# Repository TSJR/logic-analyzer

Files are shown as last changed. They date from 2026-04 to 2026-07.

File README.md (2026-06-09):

# TTL Logic Analyzer

Breadboard and PCB-based logic analyzer built from discrete 74xx TTL logic, SRAM, and multiplexed LED matrix displays.

## Overview
This project aims to build a fully discrete logic analyzer without using a microcontroller. The analyzer captures digital bus states into SRAM and displays captured samples on multiplexed LED matrices.

Project is currently in a state of active prototyping.

*This repository also contains a [closely related project](attiny-logic-analyzer) using an MCU-based design with 24 channels. 

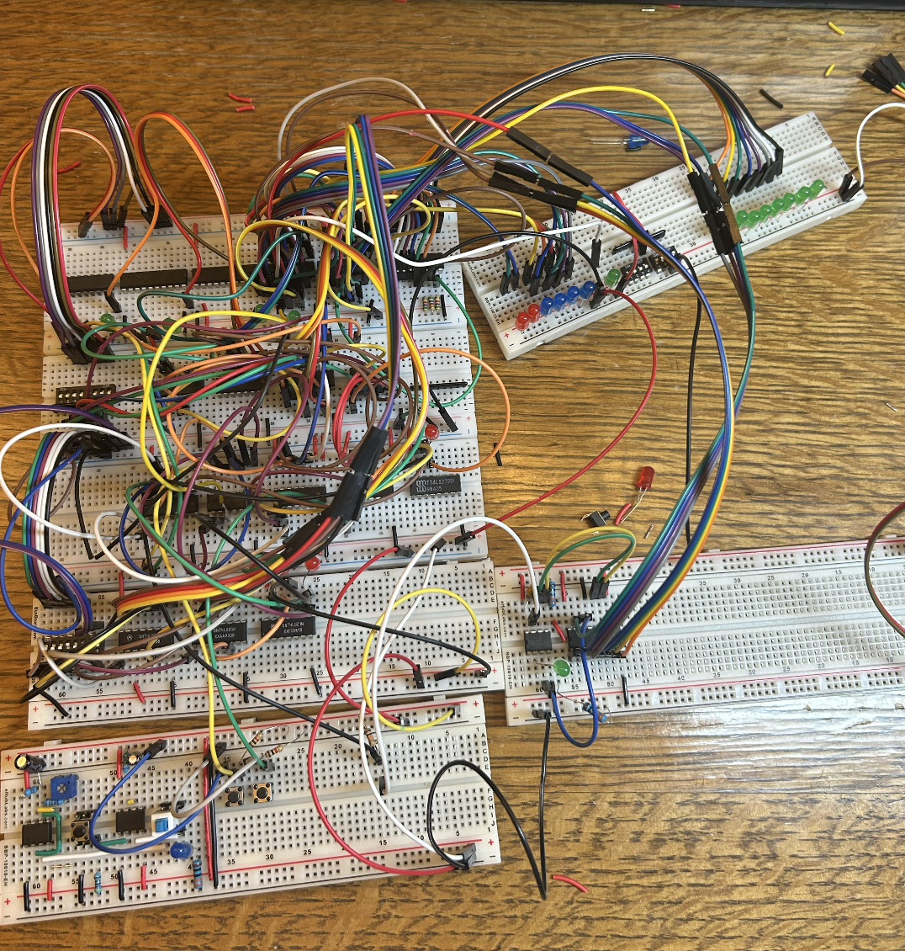
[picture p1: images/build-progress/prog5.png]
Current prototype


## Features
- Fully TTL-based architecture
- SRAM-based sample capture
- Multiplexed LED matrix display
- External/internal clock modes
- Planned trigger and halt functionality
- Modular PCB-based design

## Current Status
Current prototype supports:
- 64ish x 8 sample memory subsystem
- LED matrix display driver
- Breadboard proof-of-concept testing

Known issues:
- Breadboard noise/signal integrity
- Clock edge instability
- Limited memory

## Architecture
Main subsystems:
- Capture memory subsystem
- Address/control logic
- Clock generation and edge conditioning
- Display subsystem

## Relevant Simulation Subcircuits
- `analyzer_7400.circ` — 74xx IC Implementation     
    - **mem_64x8**: Full memory subsystem test built from 74xx-style chips using four `ram_unit` subcircuits.
    - **ram_unit**: 16x8 RAM unit built from 74xx-style chips; used as the building block for `mem_64x8`.
    - **disp_16x16**: Limited-capacity display subsystem test; does not yet include the physical driver circuitry needed for hardware.
- `analyzer_ttl.circ` — Abstract Logic Implementation
    - **mem_64x8_async**: Asynchronous version of the 64x8 memory subsystem; same capacity as the final intended design.
    - **disp_16x32**: Full-capacity display subsystem test.

More detailed documentation:
- [Analyzer Architecture](docs/architecture.md)
- [Build Log](docs/build-log.md)
- [Simulation Subcircuits](simulations/sim-subcircuits.md)

## Repository Structure
```text
docs/                   Docs and architecture notes
images/                 Build photos and diagrams
pcb/                    KiCad PCB projects
simulations/            Logisim simulations
attiny-logic-analyzer/   Related MCU-based project
```

## Hardware
Main IC families/components:
- 74xx logic family chips
- ULN2803 and UDN2981

## Future Plans
- Expand memory depth
- Modular memory pcb
- Trigger logic
- Improved clock conditioning
- PCB-based final implementation

If the project expands beyond basic TTL hardware, plans may include
- USB interface
- OLED display
- Many more channels
- Higher sampling rate 

## License
MIT License

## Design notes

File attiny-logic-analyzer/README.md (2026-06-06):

### ATtiny Logic Analyzer
24-channel ATtiny85-based logic analyzer built on a custom PCB

## Overview
This project is a tool for use in debugging other projects. It reads from 24 data inputs using 3 `74LS595` chips connected to the ATtiny85. The ATtiny then displays the inputs on an LCD screen via I2C protocol. It is asynchronous, meaning it displays what data is being read at all times, and it does not store read data. This makes it unusable for situations where consecutive sample rates are necessary, but it's helpful for taking a look at the state of a system one sample at a time. 

The first prototype of the project is complete.

## Features
- 24 channel analysis
- `74LS595` shift registers for many inputs
- ATtiny MCU
- 16x2 LCD via I2C protocol
- 3D printed housing

## Repository Structure
```text
code/               Arduino code
images/             Images of schematics and builds
models/             3D model files (STLs designed with onshape)
pcb/                KiCad schematic and PCB design
```

## License
MIT License

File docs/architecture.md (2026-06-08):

# TTL Logic Analyzer Architecture 
## Overview
- Analyzer is comprised of two halves
    - **Memory Subsystem**
    - **Display Subsystem**
- Operates in read or write mode
    - Read mode: data is read from **Memory Subsystem** and is output on the **Display Subsystem**
    - Write mode: on each clock pulse, data from target device is sequentially saved into **Memory Subsystem**
## Design Goals
- Entire system built on 74xx chips (no MCU)
- Modular enough to increase memory capacity/display size
- Capable of capturing 64 samples
- Capable of displaying samples with vertical and horizontal scrolling
## Analyzer I/O
### Target device connections
- **CLK**: target device clock
- **Data In**: 8 channels of target device
- **GND**: common ground between analyzer and target device
### System Controls
- **RUN** (active LOW): enables write mode 
- **HLT** (active HIGH): enables read mode
- **HLT Word EN** (active HIGH): enables word-based halting 
- **HLT Word**: defines 8-bit input where the analyzer should halt
## Example Usage
1. **HLT Word EN** is tied low to disable word-based halting
2. **CLK**, **Data In**, and **GND** are connected to target device
3. **RUN** is briefly pulled LOW, putting analyzer into write mode
4. On each clock pulse, data from the target device is saved to the **Memory Subsystem**
5. **HLT** is briefly pulled HIGH, putting the analyzer into read mode
6. The **Display Subsystem** addresses data from the **Memory Subsystem** and displays it on LED matrices

## Memory Subsystem Architecture
The memory subsystem captures 8-bit parallel data from a target device and stores sequential samples into RAM using an internally clocked address counter.  

**Capacity**: 64 samples x 8-bit sample size

___
### Memory Subsystem Interface
Inputs:
- **CLK**: target clock used for sampling
- **Data In**: 8-bit captured input bus
- **RUN**: enters write mode
- **HLT**: enters read mode
- **HLT Word EN**: enables automatic halt matching
- **HLT Word**: 8-bit halt-match value
- **Address In**: external read address from **Display Subsystem**

Outputs:
- **Data Out**: 8-bit stored sample output to **Display Subsystem**
- **R/W State**: current analyzer mode
___
## Memory Subsystem Organization
### R/W Mode Control
R/W state is stored in SR-latch  
- SR-latch set = write mode  
- SR-latch reset = read mode

The latch is manually reset through briefly bringing the **HLT** signal high or automatically through word-based halting logic. The latch is reset by briefly bringing the **RUN** signal high
___
### RAM Units (4 total)
Each unit is constructed with:
- 1 RAM chip for high 4 bits
- 1 RAM chip for low 4 bits
- 1 octal tri-state buffer
Total of 16 samples with 8 bits of data per unit

Demultiplexer chip uses upper 2 address bits to select active RAM unit (both both RAM and buffer side)

All tri-state buffer outputs connect forming the data bus. Since the `74189` chip has inverted outputs, the bus must be negated with hex inverters before becoming **Data Out**
___
### Addressing
System supports internal (**Memory Subsystem**'s 6-bit counter) and external addressing (**Display Subsystem**'s 6-bit counter)

Internal addressing (write mode)
- Clock pulse advances the **Memory Subsystem**'s counter
- **Data In** is written into memory

External addressing (read mode)
- **Display Subsystem** is able to cherry pick saved data from the **Memory Subsystem** and display it

In both addressing modes, the upper 2 address bits select a RAM unit and lower 4 address bits select the current location in memory
___
### Clocking and Write Control
Two operations per clock cycle during write mode
- On rising edge, data is written to RAM
- On falling edge, internal counter is incremented
**Data In** is only written to the demultiplexer's selected RAM unit

Clock is ignored in read mode as memory contents are to be accessed asyncronously
___
### Halting Modes
- Word-based Halting
    - Enters read mode when **Data In** matches user-defined 8-bit sequence **HLT Word** on clock pulse. Mode is only available when **HLT Word EN** is tied high
- Manual Halting
  - Enters read mode when **HLT** is pulled high
  - Available regardless of **HLT Word EN**'s state.

Neither halting mode takes a data sample when the halt word is detected to maximize the analyzer's limited memory

## Operating Mode Flows
### Read Mode
1. System is halted
   -  **HLT** pulled high or **Data In** matches **HLT Word** during word-based halting mode
2. SR-latch is reset
3. Selector chips route **Address In**, allowing **Display Subsystem** to address **Memory Subsystem** asyncronously
### Write Mode
1. **Run** is pulled high
2. SR-latch is set
3. Selector chips route internal counter
4. Internal counter is reset
5. High clock pulse writes data into RAM at memory location
6. Low clock pulse advances counter and targets next RAM memory location
n 

## Current Limitations
- 64 total samples
- 8-channel capture width
- May only work with low-frequency systems
- No internal clock
- No timestamp tracker

## Future Improvements
- 128 samples and/or 16-channel capture width
- Less primitive display (higher resolution/colors)
- Internal clock implementation
  - User-defined sample rate
  - Manual sampling with button
- If project moves away from being exclusively TTL
  - USB interface
  - Microcontroller usage
  - RAM upgrade (eg. 6116 or 6264 SRAM)

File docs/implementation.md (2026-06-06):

# TTL Logic Analyzer Implementation
## Overview
- Analyzer is comprised of two halves
    - **Memory Subsystem**
    - **Display Subsystem**
- Operates in read or write mode
    - Read mode: data is read from **Memory Subsystem** and is output on the **Display Subsystem**
    - Write mode: on each clock pulse, data from target device is sequentially saved into **Memory Subsystem**
## Memory Subsystem
### 74xx Hardware
- 8 `74189` RAMs
- 2 `74LS157` selectors
- 2 `74LS161` binary counters 
- 2 `74LS14` hex inverter/schmitt trigger
- 1 `74LS32` OR gate chip
- 2 `74LS85` 4-bit comparators
- 1 `74LS21` quad input AND gate
- 1 `74LS279` SR-latch chip
- 4 `74LS245` octal tristate buffers
- 2 `74LS08` AND gates
- 1 `74LS139` decoder
### Additional Hardware
- 8x `1088AS` 8x8 dot matrix
- 32x 5-10k pullup resistors
- unknown amount of breadboards
- a lot of wires

## Build
### RAM Units
The memory subsystem contains 4 RAM units. Each RAM unit is comprised of:
- 2 `74189` 16x4 RAM ICs
- 8 pullup resistors
- 1 `74LS245` octal tri-state buffer

Connections are as follows:
- **Data In Bus**[7:4] to data inputs of first `74189`
-  **Data In Bus**[3:0] to data inputs of second `74189`
- All 8 `74189` outputs are pulled high and connected to side A of `74LS245`
- Side B of `74LS245` is connected to **Data Out Bus**
- The `74LS245` is wired for A->B operation

## Display Subsystem
## Timing/Control Logic
## Bus Architecture
### Data Bus
### Address Bus
## Known Issues
## Implementation notes

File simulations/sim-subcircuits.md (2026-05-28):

# Simulation Subcircuits

## `analyzer_7400.circ` — 74xx IC Implementation

- **main**: Current implementation connecting the memory subsystem (`mem_16x8`) to the display subsystem (`disp_16x16`).
- **mem_64x8**: Full memory subsystem test built from 74xx chips using 4 `ram_unit` subcircuits.
- **ram_unit**: 16x8 RAM unit built from 74xx  chips; used as building block for `mem_64x8`.
- **mem_16x8**: Limited-capacity memory subsystem test; reflects the current working design
- **disp_16x16**: Limited-capacity display subsystem test; does not include the physical driver circuitry needed for hardware

## `analyzer_ttl.circ` — Abstract Logic Implementation

- **main**: Current implementation connecting `mem_64x8_async` to the display subsystem (`disp_16x32`).
- **mem_64x8_async**: Asynchronous version of the 64x8 memory subsystem; same capacity as the final intended design
- **mem_64x8**: Original 64x8 memory subsystem design; same capacity as the final intended design
- **disp_16x32**: Full-capacity display subsystem test

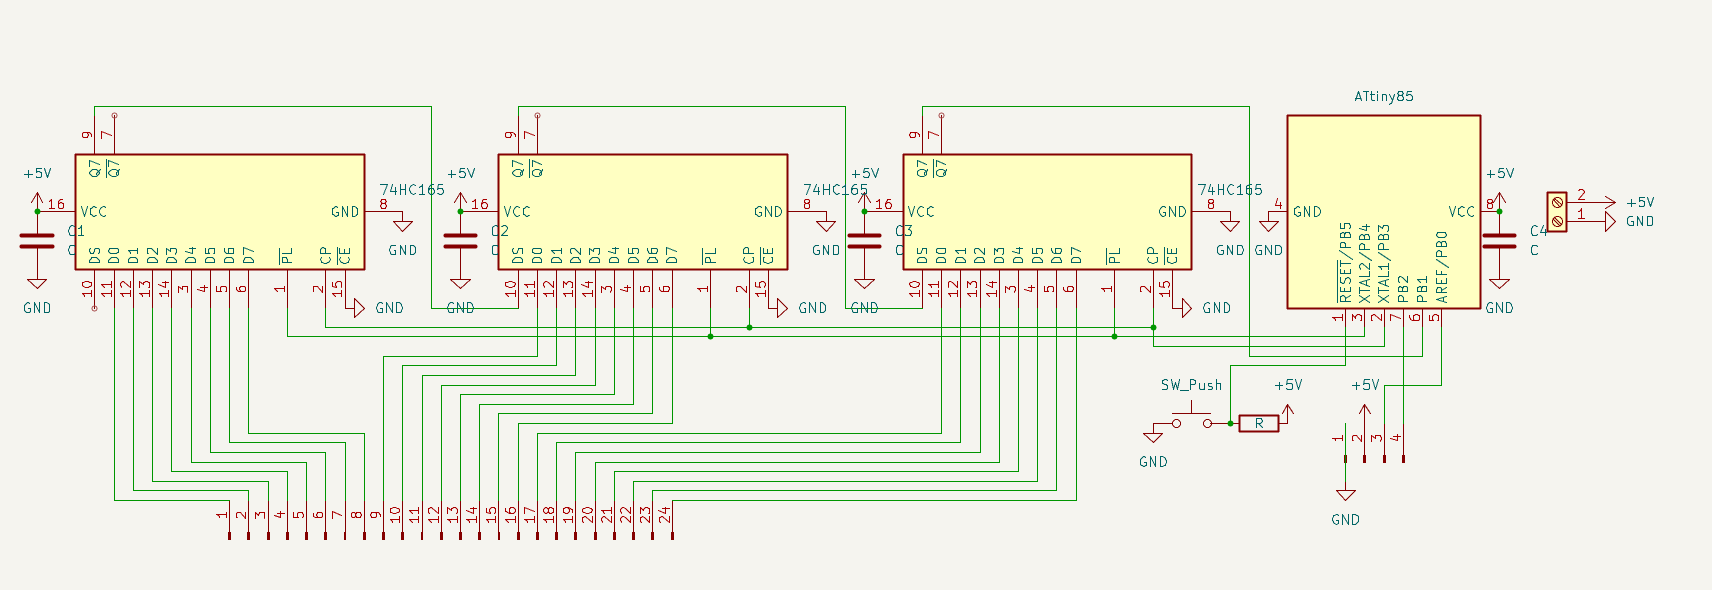
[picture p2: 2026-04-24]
attiny-logic-analyzer/images/attiny_schematic.png

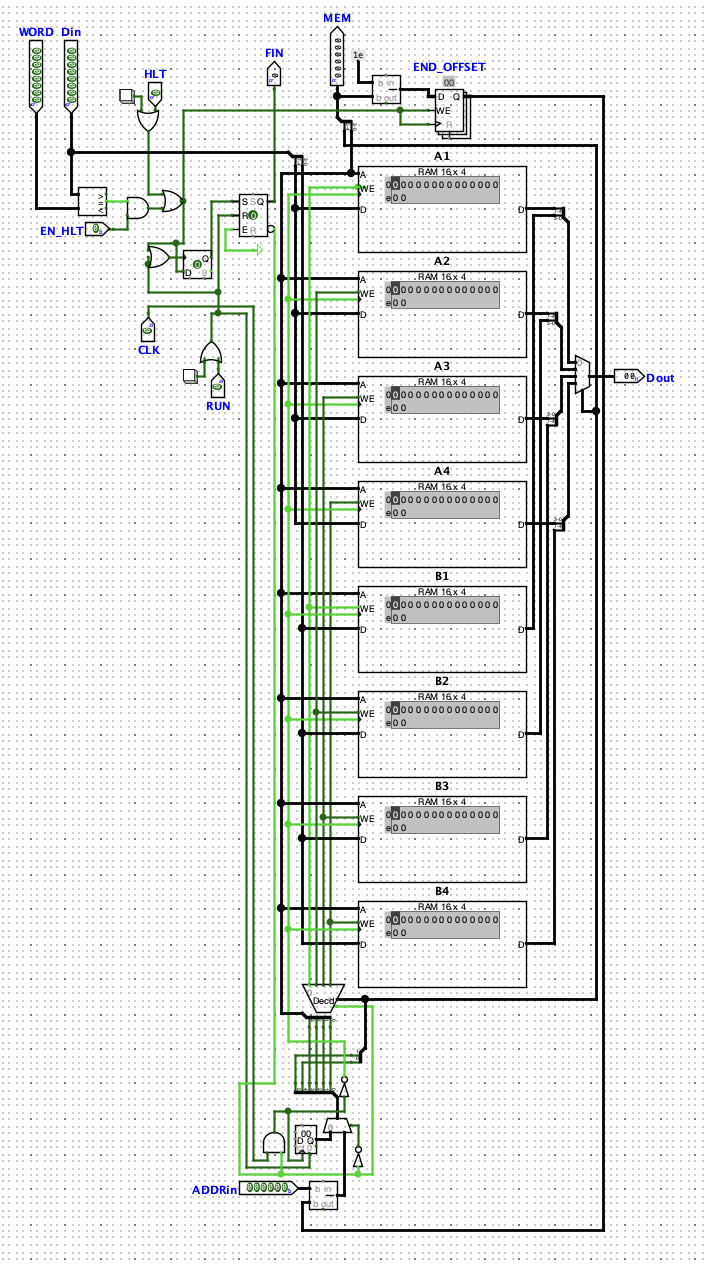
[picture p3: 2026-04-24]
images/ttl_mem_64x8_sim.png

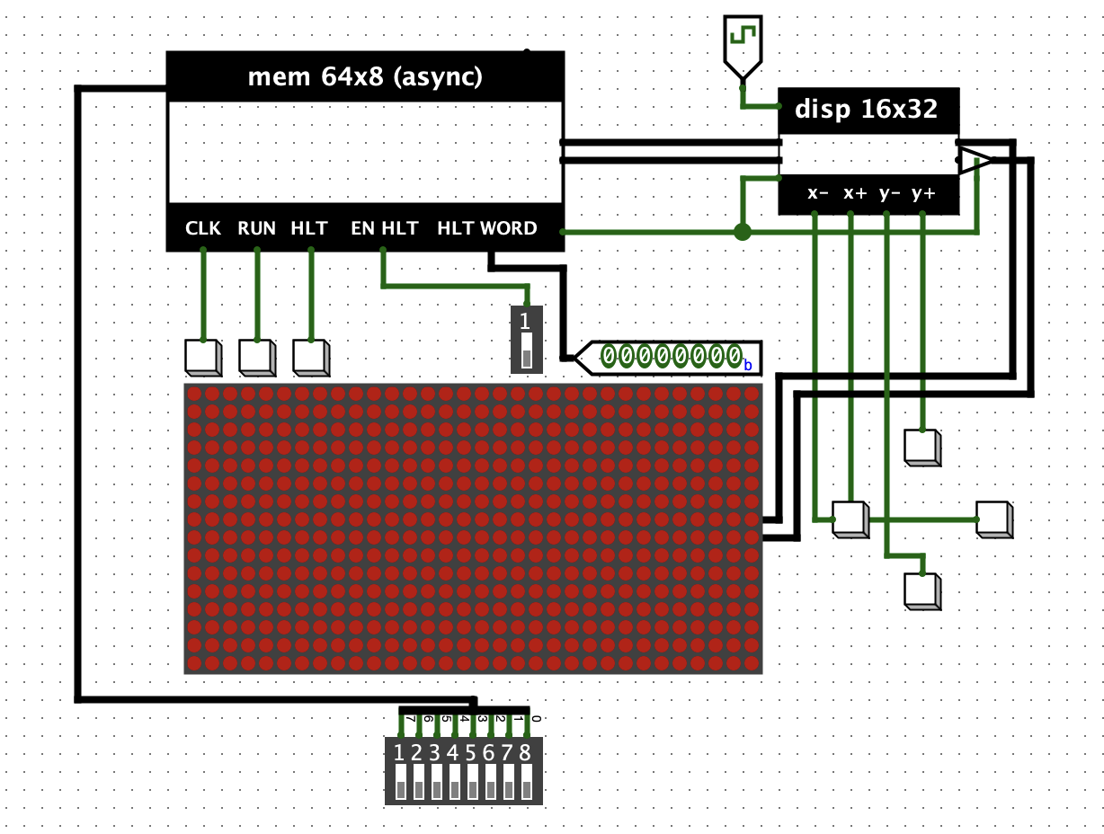
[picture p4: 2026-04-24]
images/ttl_analyzer_full_sim.png

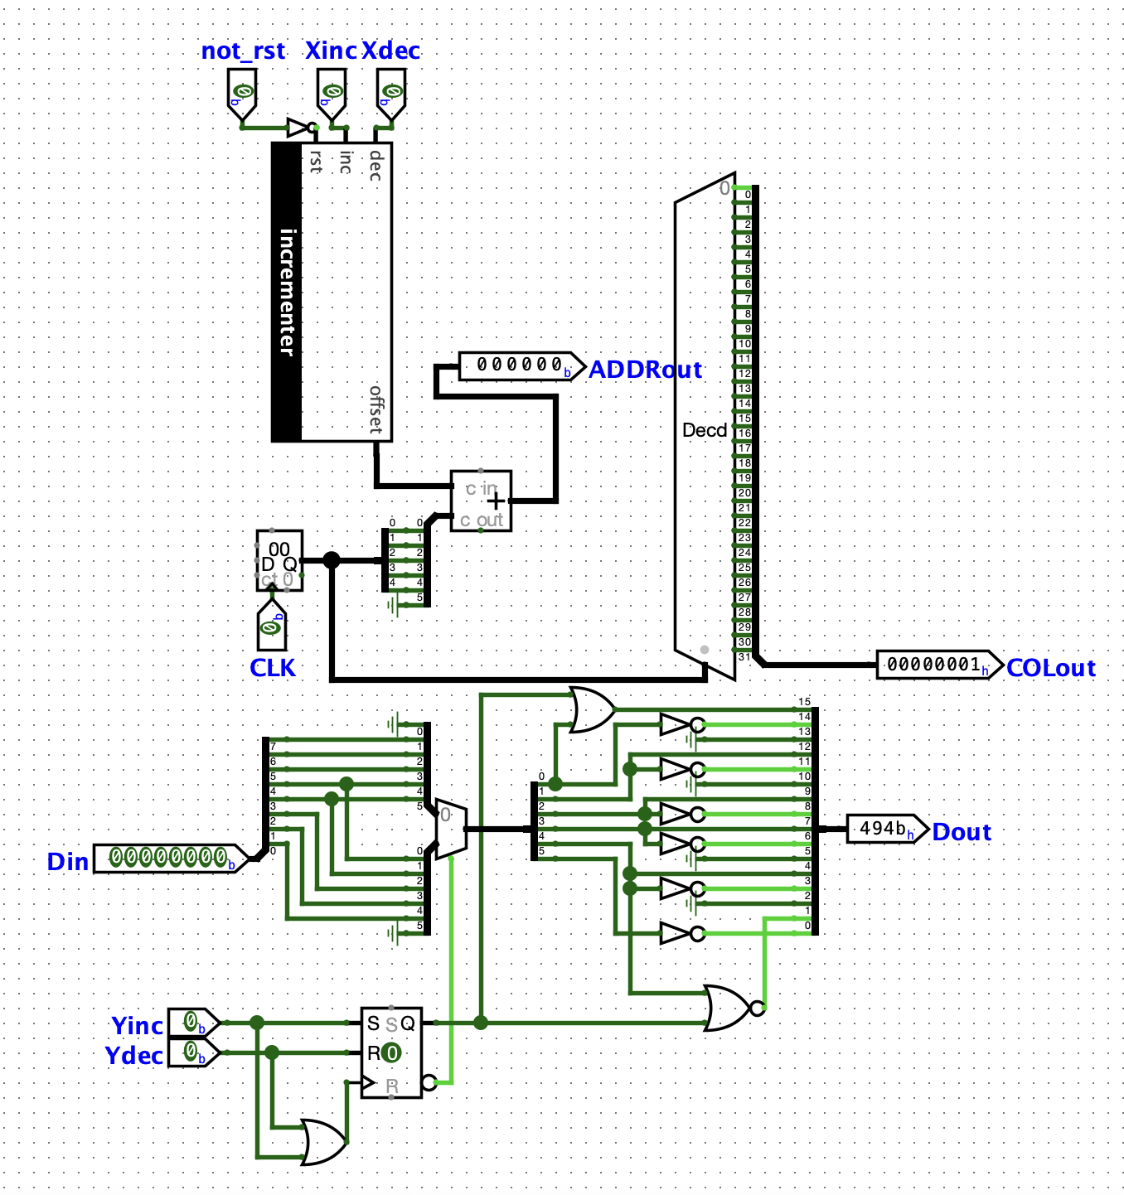
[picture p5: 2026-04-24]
images/ttl_disp_16x32_sim.png

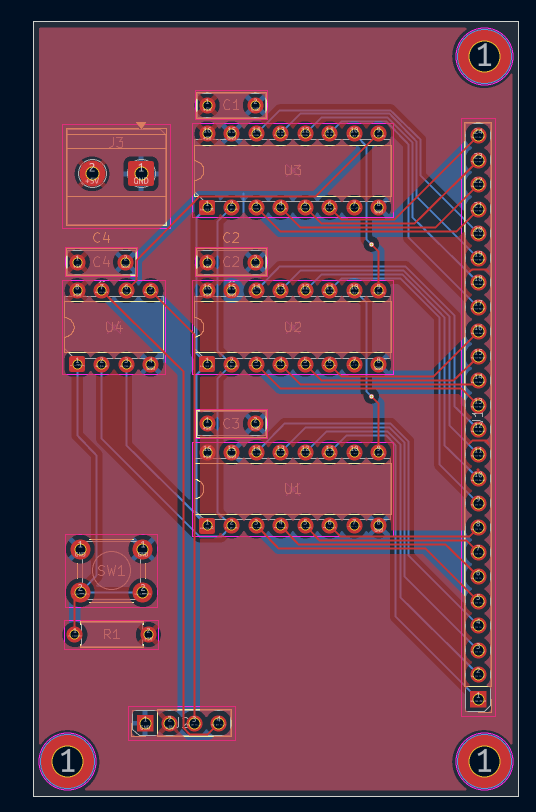
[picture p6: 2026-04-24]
attiny-logic-analyzer/images/attiny_pcb.png

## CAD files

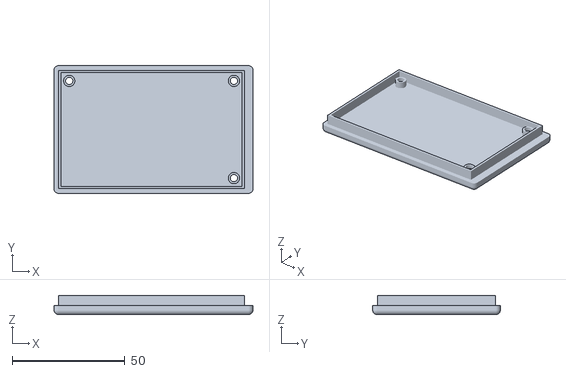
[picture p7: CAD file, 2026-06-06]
attiny-logic-analyzer/models/housing/back.stl
88.4 x 56.7 x 8.51

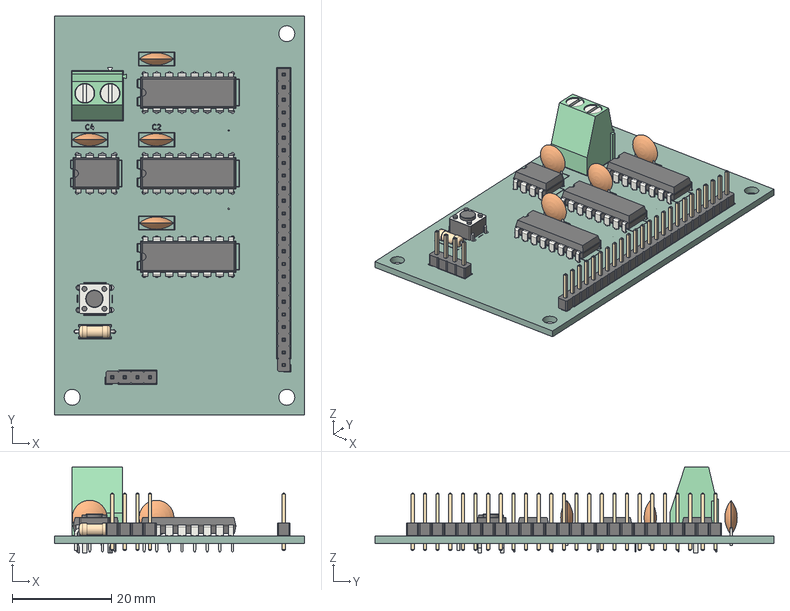
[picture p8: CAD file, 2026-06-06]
attiny-logic-analyzer/pcb/pcb.step
50.3 x 80.3 x 17.3 mm
SW_PUSH_6mm
PinHeader_1x24_P2.54mm_Vertical
DIP-16_W7.62mm x 3
R_Axial_DIN0207_L6.3mm_D2.5mm_P7.62mm_Horizontal
C_Disc_D7.0mm_W2.5mm_P5.00mm x 4
PinHeader_1x04_P2.54mm_Vertical
TerminalBlock_Phoenix_MKDS-1,5-2-5.08_1x02_P5.08mm_Horizontal
DIP-8_W7.62mm
Logic Analyzer_silkscreen
Logic Analyzer_PCB

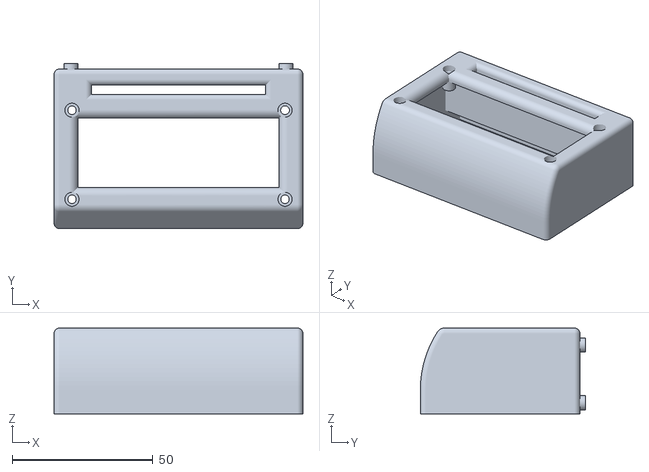
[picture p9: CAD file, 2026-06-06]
attiny-logic-analyzer/models/housing/body.stl
88.4 x 58.7 x 30.5

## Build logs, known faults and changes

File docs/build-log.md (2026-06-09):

# TTL Logic Analyzer Build Log
## 5/22
Built bare minimum driver for a single 8x8 dot matrix as a test for display subsystem. 

Rows (matrix anodes) were driven by a high-sidedriver controlled by hardcoded inputs. A binary counter was connected to a 3-8 demultiplexer to select the active column, whose signal controlled a low-side driver. Driver output was connected via 330 ohm resistors to the columns (matrix cathodes).

Ben Eater's design of 555 timer-based clock module was used for incrementing the binary counter. 

Note: A `74LS138` was used as the demultiplexer since it was what was on hand, but it uses active low signalling so it effectively selects 7 columns at once. Its outputs were negated with 2 `74LS14` chips. A `74LS238` (active high) will be used in the future to improve the design.

___
### 8x8 Dot Matrix Driver
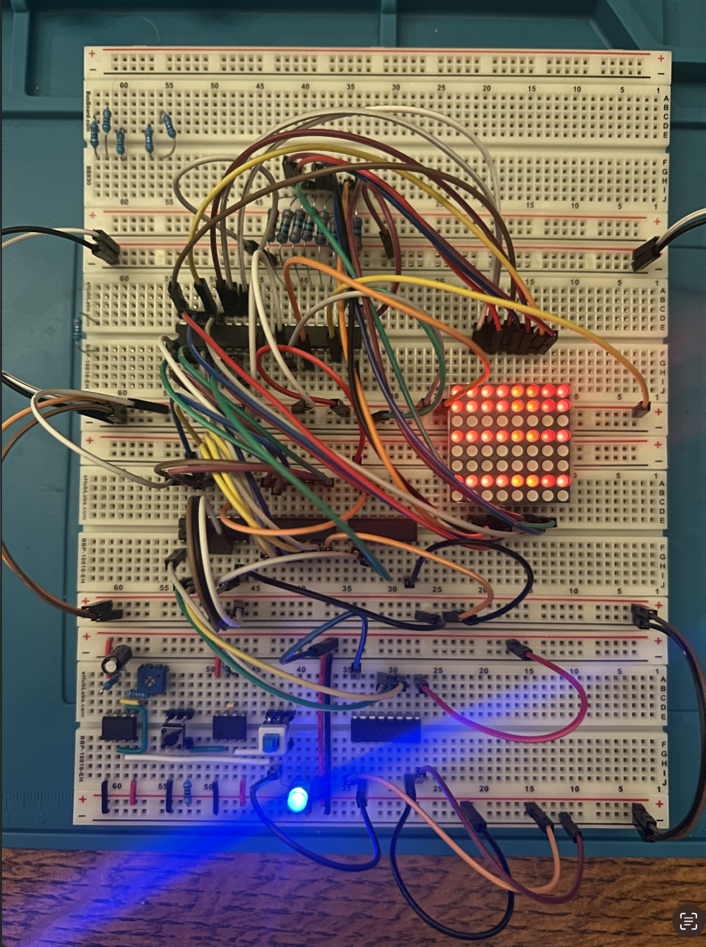
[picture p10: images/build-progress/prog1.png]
Dot matrix driver


### Components
- 1 `UD2981` (high-side  driver)
- 1 `ULN2803` (low-side driver)
- 1 `74LS138` (3-8 demulitplexer) 
- 1 `74LS14` (hex inverter/schmitt trigger)
- 1 `74LS161` (binary counter)
- Too many 104 caps and 8x 330 ohm resistors

### Results/Future
- Good compatability between `UDN2981` and `ULN2803`
- Need polished [breadboard-compatible PCB](../pcb/8x8) for better breadboard prototyping
- Need to check scalability (final to have 8 total matrices)

## 5/23
Built 16x8 memory subsystem laid out in [simulation](../simulations/analyzer_7400.circ), though halt word enable system and RAM output inversions were omitted for simplicity.

**Design change #1**: `74LS245` tri-state buffer added to avoid having to build a 32-8 line multiplexer. Each RAM unit will have a buffer whos outputs are shared.

**Design change #2**: `74189` chips have open collector output (not consider in simulation), so 10k pull-up resistors were added.

**Design change #3**: Incoming clock signal had to be converted to rising edge via RC circuit (not considered in simulation). Implementing this meant passing the clock pulse through an RC circuit and into a schmitt trigger, effectively negating the clock pulse. The circuit had to be redesigned with this in mind.

**Potential design change**: D flip-flop might be completely unnecessary. Though in the original design it made for sample buffering (sampled data on the clock pulse when analyzer was halted), this may be removed entirely. It would make the system significantly more simple, and it makes sense to limit the number of samples given the already limited 64 sample memory.

**Design change updates reflected in current simulation as of _(5-27-2026)_**

___
### 16x8 Memory Subsystem
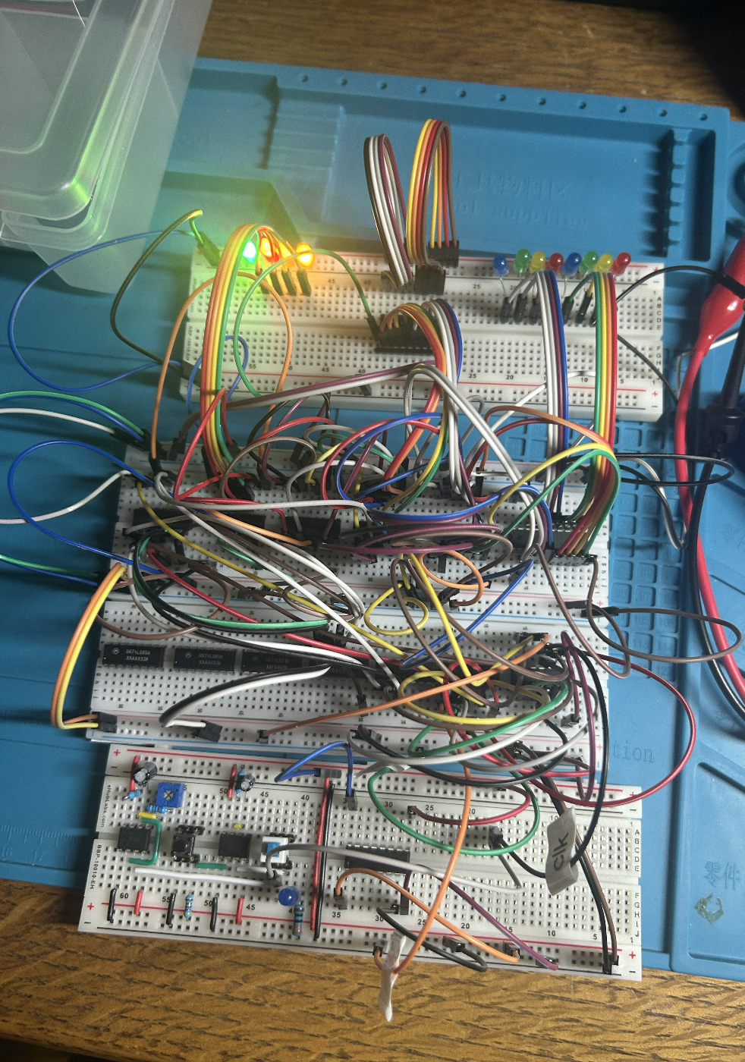
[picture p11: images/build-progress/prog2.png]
16x8 memory subsystem


### Components
- 2 `74189` (RAM)
- 1 `74LS157` (2-1 multiplexer)
- 1 `74LS161` (binary counter)
- 1 `74LS279` (SR-latch)
- 1 `74LS74` (D flip-flop)
- 1 `74LS32` (OR gate)

After the memory subsystem was finished, it was connected to the matrix driver for a quick test. Its behavior was quite unpredictable, likely due to button debouncing and the edge detection circuit.

___
### 16x8 Memory Subsystem with Matrix Driver
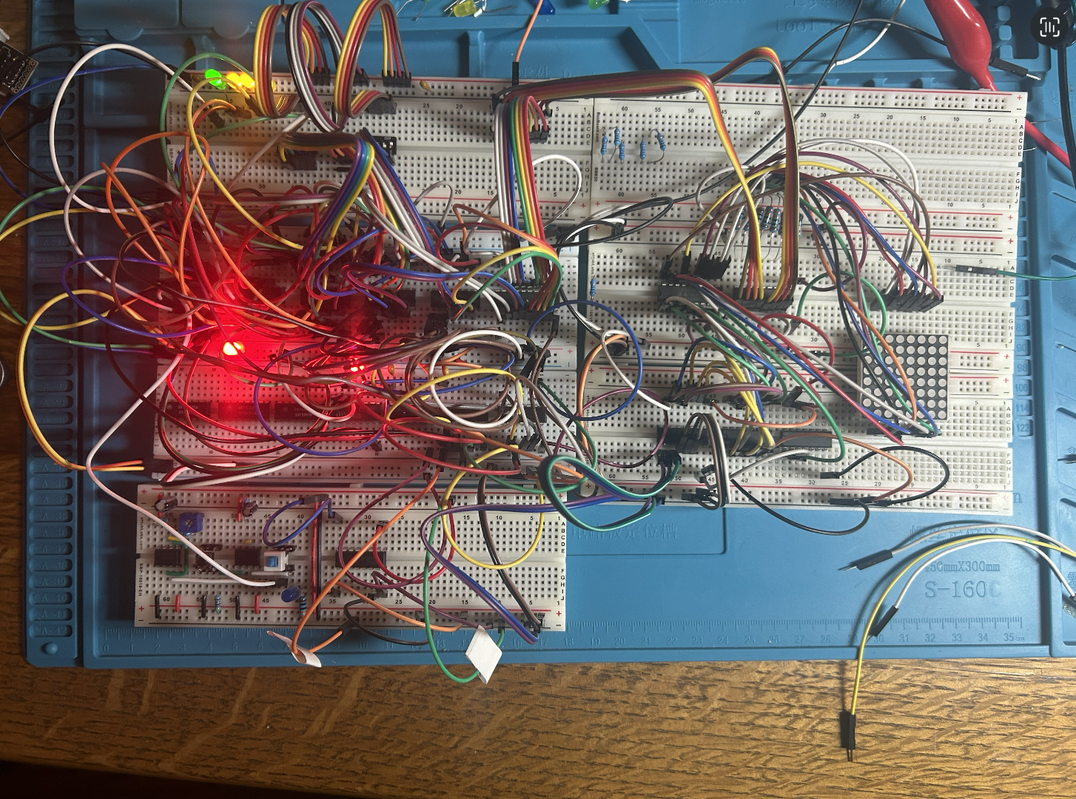
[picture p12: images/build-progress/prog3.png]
16x8 memory subsystem w/ matrix driver


### Results/Future
- Major noise despite a plethora of 104 caps. This size memory unit is probably the maximum that can be built on breadboards. Moving forward it will be done on modular PCBs. 
- Reconsider clock gating on RAM chips since 74xx they aren't meant for high frequency operations.
- Redesign simulation w/ design changes
- If simulation still works, rebuild the entire system (still only 16x8, but possibly with a "dummy" secondary RAM unit to test RAM unit selection). 

## 6/4
Built 64x8 memory subsystem laid out in [simulation](../simulations/analyzer_7400.circ).Only one memory unit was fully built: the other 3 were "dummy" units built with `74LS245`chips. Comparators and quad input AND gate were omitted for simplicity. 

The 6-bit **Address In** was represented by an 8-bit DIP switch pulled low by 5k ohm resistors connected to the `74LS157` chip inputs. The **Data In** bus was another 8-bit DIP switch pulled low by 5k ohm resistors connected directly to the RAM unit. The high 4 bits were connected to the first `74189` and the low 4 bits were connceted to the second. **HLT** and *RUN** were tied high and low with jumper wires for easy mode swaps. 

Ben Eater's design of 555 timer-based clock module was used as the clock input. Its output was inverted with the `74LS14` since the system is meant to run on the falling edge of clocks.

### Components
- 2 `74189` (RAM)
- 4 `74LS245` (tristate buffer)
- 2 `74LS157` (2-1 multiplexer)
- 2 `74LS161` (binary counter)
- 1 `74LS279` (SR-latch)
- 1 `74LS32` (OR gate)
- 1 `74LS14` (Schmitt trigger/NOT gate)

### Results/Future
The circuit didn't work. During read mode (SR latch set) counter data was correctly selected by the `74LS157` chips, but during write mode the **Address In** from the DIP switch was not correctly selected. The active address was shown as being all 1's no matter what. Using the multimeter, the problem was tracked to the output of the `74LS157` chips.

Data was not correctly written to the RAM. Data should have been written when inverted clock went low (while button of the clock module was pressed). After writing data, RAM address was manually selected with jumpers (since **Address In** was useless) and data was not being correctly represented from the `74LS245`.

Unsure what the cause of either issue is. Going to debug with a multimeter in coming days.

## 6/5
Debugged memory subsystem:
- Completely rewired RAM unit so only one RAM chip is connected to the system
- Replaced RAM inputs so they're hardcoded with jumper wires
- Confirmed `74189` chips work as expected (write when CS and WE are low)
- Used multimeter to check `74LS157` chips: found 5k resistors were too high -> replaced with 1k resistors -> fixed!
- Used multimeter to check outputs (side B) of `74LS245`: no output
- Hardcoded inputs (side A) of `74LS245`: found still no output
- RAM chips were fine: problem was the `74LS245`: pin 1 (`DIR`) was low but should have been high -> swapped jumper cable position -> fixed!

## New Ideas
- Give option for input clock being on rising edge too
- It's possible that when analyzer a target system, the channels will not register the highs and lows correctly (eg target system's high state is too low for the 74xx chip inputs): may need to use a sort of amplifier, or maybe PUD resistors will suffice

___
### 64x8 Memory Subsystem (w/o **HLT Word**)
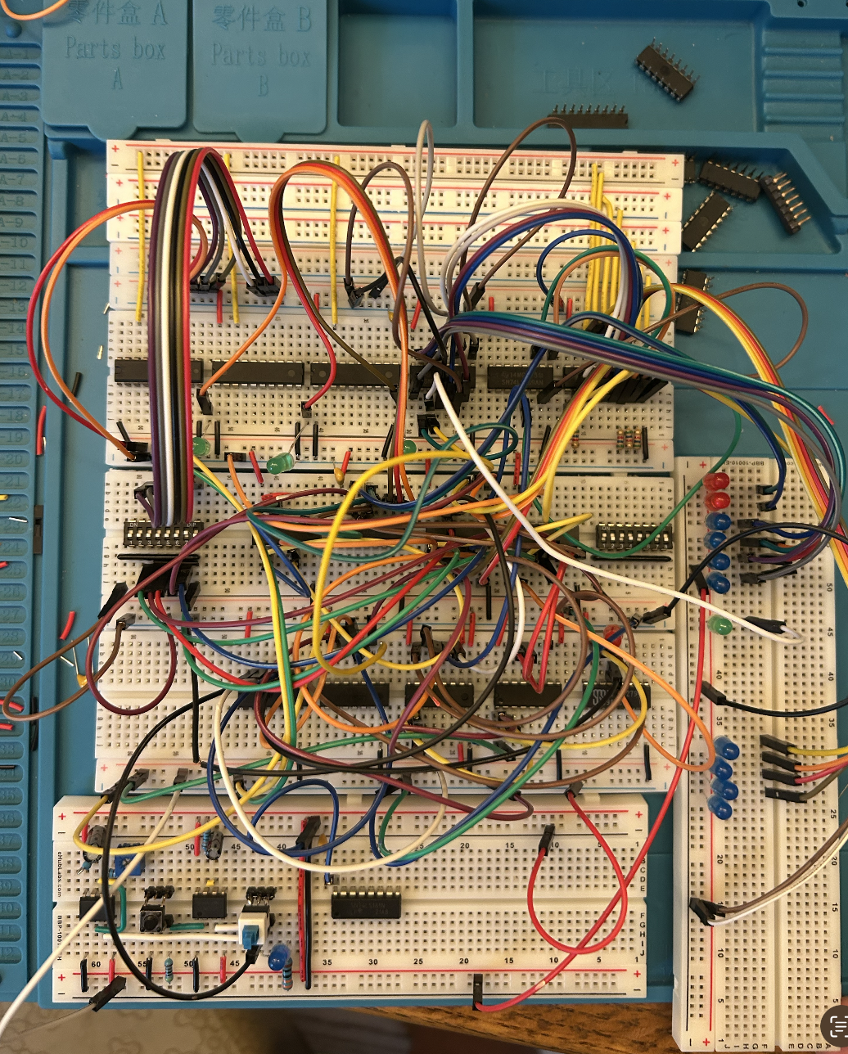
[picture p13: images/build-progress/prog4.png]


### Results/Future
- Rewire disconnected RAM chip
- Rewire RAM inputs for testing
- Add word-based halting (comparators and quad input and gate)
- Thoroughly test entire circuit including tests with different clocks
- Build display subsystem

## 6/7
Polished 64x8 memory subsystem to prepare it for testing
- Rewired RAM
- Added 8 bit DIP switch
- Added buttons for **HLT** and **RUN**
- Rewired incorrect RAM outputs (bit order was flipped on several pins)

### Results/Future
- Tests went well: 
    - Memory is written to RAM units during write mode as expected
    - Memory is being read from bus during read mode as expected
- Add hardware for **HLT Word** (comparators)
- Add word-based halting
- Build display subsystem
- Rigorous testing

## 6/8
Added hardware for **HLT Word** matching the [simulation](../simulations/analyzer_7400.circ) with a key change: pin 10 of the `74LS21` quad input AND gate was tied to the inverted clock signal. This way, the system is only halted on a clock pulse. 

This improvement introduced a major timing bug. When a clock pulse occurred while the halt word was detected, the 74LS279 SR latch immediately reset, placing the system into read mode. Because the RAM write-enable (/WE) signal was still active for a short period due to propagation delay through the control logic, the address multiplexer switched to the external read address (0000) before write mode was fully disabled. As a result, memory address 0000 was unintentionally overwritten with the **HLT Word**.

The issue was resolved by directly gating the halt signal into the RAM write-enable logic, ensuring that halt detection immediately forced /WE inactive before any control-state transitions could occur.

Built a sample target device with an ATtiny85 and a `74LS595` shift register. Tested writing values up to speeds of 10ms low clock pulses. When testing with an external devices, a few problems showed up:
- When clock is floating the the analyzer is in read mode, it starts writing nonsense memory rapidly
- If **Data In** is not explicity set, unpredictable values are written to memory

These problems would make the analyzer incredibly painful to use. Issues were fixed with 10k resistors: one resistor tie clock input high while 8 tie **Data In** low by default. It's important to note that the clock still goes through a `74LS14` NOT gate/Schmitt trigger for cleanup. 

**Potential problem:** If user wants less than 64 samples, garbage RAM data remains. 2B1S solution:
- Make final used RAM address accessable to display subsystem
- Block horizontal scrolling past last used RAM address (problem for carousaled data)
- Allows display to end at final sample to avoid unecessary scrolling

Limitations:
- Assumes user takes at least 32 samples
- Requires automatical halting after 64 samples
- May have to build a separate circuit for clearing all 64 memory spaces
___
### 64x8 Memory Subsystem
64x8 memory subsystem

### Results/Future
- Resistor/Schmitt trigger combo seem to fix floating problems
- Analyzer works are (relatively) high clock pulses
- Build display subsystem
- Design PCB schematic for memory subsystem

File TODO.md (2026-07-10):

## TODO
### docs/
- architecture.md
    - [ ] add display subsystem 
    - [ ] add high-level block diagram (figma?)
- implementation.md
    - [ ] add low-level display subsystem
- timing.md
    - [ ] add timing diagram image
    - [ ] write timing explanation
### simulations/
- analyzer_74xx.circ
    
## Completed
- [x] added memory subsystem to architecture.md *(5-27-2026)*
- [x] added 5/22 display driver test to build-log.md *(5-27-2026)*
- [x] added 5/23 16x8 memory subsystem test to build-log.md *(5-27-2026)*
- [x] designed 74xx 64x8 memory subsystem  *(5-28-2026)*

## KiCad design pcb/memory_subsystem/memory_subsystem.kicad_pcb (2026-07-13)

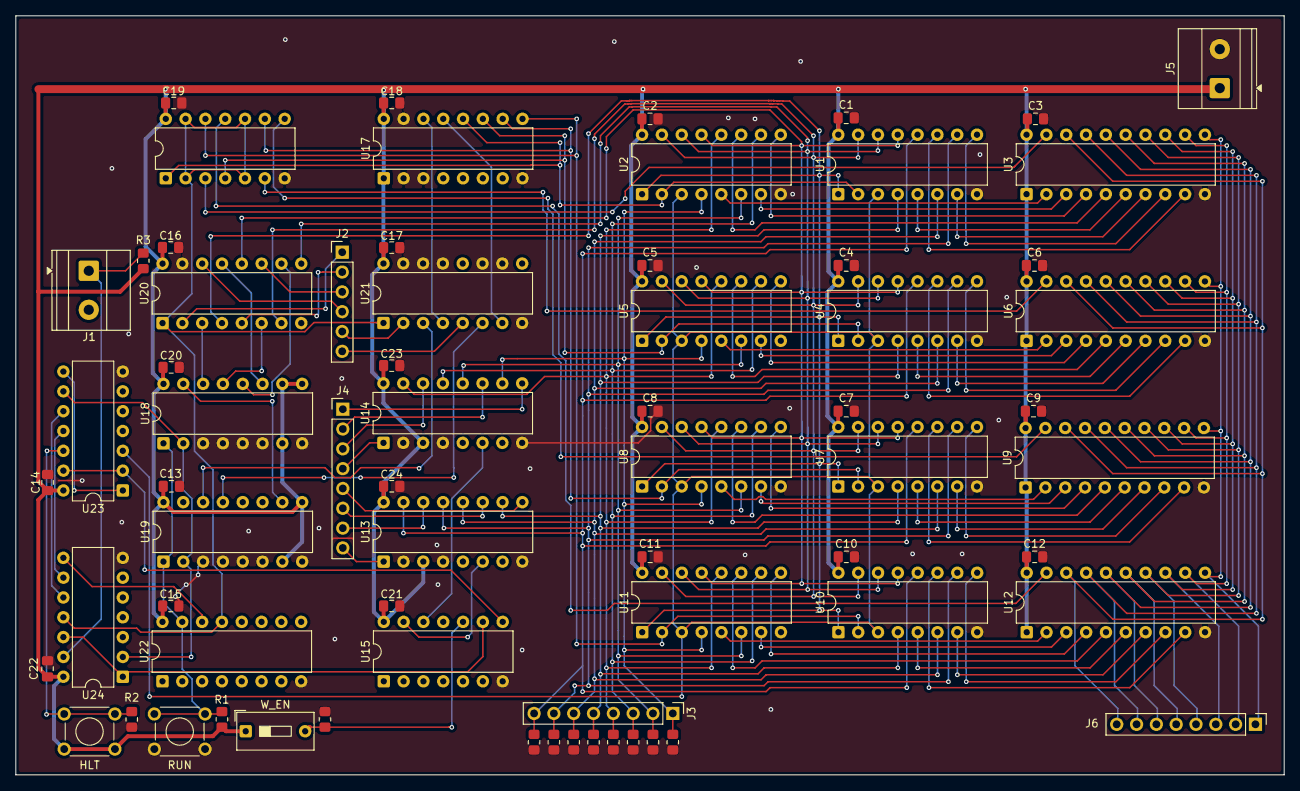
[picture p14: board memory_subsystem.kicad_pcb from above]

Board: 2 copper layers, 162.6 x 97.3 mm, 69 parts (0 on the bottom side), 100 nets.

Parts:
C1, C2, C3, C4, C5, C6, C7, C8, C9, C10, C11, C12, C13, C14, C15, C16, C17, C18, C19, C20, C21, C22, C23, C24: C; C_0805_2012Metric_Pad1.18x1.45mm_HandSolder
HLT: HLT; SW_TH_Tactile_Omron_B3F-100x
J1: CLK; TerminalBlock_Phoenix_MKDS-1,5-2_1x02_P5.00mm_Horizontal
J2: Addr In; PinHeader_1x06_P2.54mm_Vertical
J3: Data In; PinHeader_1x08_P2.54mm_Vertical
J4: Word In; PinHeader_1x08_P2.54mm_Vertical
J5: Power; TerminalBlock_Phoenix_MKDS-1,5-2_1x02_P5.00mm_Horizontal
J6: Data Out; PinHeader_1x08_P2.54mm_Vertical
R1, R2, R3, R4, R5, R6, R7, R8, R9, R10, R11, R12: R; R_0805_2012Metric_Pad1.20x1.40mm_HandSolder
RUN: RUN; SW_TH_Tactile_Omron_B3F-100x
U1, U2, U4, U5, U7, U8, U10, U11: DIP-16_W7.62mm
U3, U6, U9, U12: 74LS245; DIP-20_W7.62mm
U13, U14: 74LS85; DIP-16_W7.62mm
U15: 74LS21; DIP-14_W7.62mm
U16, U23: 74LS32; DIP-14_W7.62mm
U17: 74LS139; DIP-16_W7.62mm
U18, U19: 74LS161; DIP-16_W7.62mm
U20, U21: 74LS157; DIP-16_W7.62mm
U22: 74LS279; DIP-16_W7.62mm
U24: 74LS14; DIP-14_W7.62mm
W_EN: W_EN; SW_DIP_SPSTx01_Slide_9.78x4.72mm_W7.62mm_P2.54mm

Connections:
+5V: C1.1, C2.1, C3.1, C4.1, C5.1, C6.1, C7.1, C8.1, C9.1, C10.1, C11.1, C12.1, C13.2, C14.2, C15.2, C16.2, C17.1, C18.2, C19.2, C20.2, C21.2, C22.2, C23.2, C24.2, HLT.1, J5.1, R1.1, R3.2, U1.16 (VCC), U2.16 (VCC), U3.1 (A->B), U3.20 (VCC), U4.16 (VCC), U5.16 (VCC), U6.1 (A->B), U6.20 (VCC), U7.16 (VCC), U8.16 (VCC), U9.1 (A->B), U9.20 (VCC), U10.16 (VCC), U11.16 (VCC), U12.1 (A->B), U12.20 (VCC), U13.3 (Ia=b), U13.16 (VCC), U14.3 (Ia=b), U14.16 (VCC), U15.14 (VCC), U16.14 (VCC), U17.1 (E), U17.16 (VCC), U18.7 (CEP), U18.9 (~PE), U18.10 (CET), U18.16 (VCC), U19.7 (CEP), U19.9 (~PE), U19.16 (VCC), U20.16 (VCC), U21.16 (VCC), U22.16 (VCC), U23.14 (VCC), U24.14 (VCC), W_EN.1
/Address Selector/Addr0: J2.1, U20.2 (I0a)
/Address Selector/Addr1: J2.2, U20.5 (I0b)
/Address Selector/Addr2: J2.3, U20.11 (I0c)
/Address Selector/Addr3: J2.4, U20.14 (I0d)
/Address Selector/Addr4: J2.5, U21.2 (I0a)
/Address Selector/Addr5: J2.6, U21.5 (I0b)
/Address Selector/CS0: U1.2 (CS), U2.2 (CS), U16.1, U17.12 (O0)
/Address Selector/CS1: U4.2 (CS), U5.2 (CS), U16.4, U17.11 (O1)
/Address Selector/CS2: U7.2 (CS), U8.2 (CS), U16.9, U17.10 (O2)
/Address Selector/CS3: U10.2 (CS), U11.2 (CS), U16.12, U17.9 (O3)
/Address Selector/OE0: U3.19 (CE), U16.3
/Address Selector/OE1: U6.19 (CE), U16.6
/Address Selector/OE2: U9.19 (CE), U16.8
/Address Selector/OE3: U12.19 (CE), U16.11
/Address Selector/RUN: R1.2, RUN.2, U18.1 (~MR), U19.1 (~MR), U22.15 (~S)
/Address Selector/R/W: U16.2, U16.5, U16.10, U16.13, U20.1 (S), U21.1 (S), U22.13 (Q), U24.11
/Address Selector/SAddr0: U1.1 (A0), U2.1 (A0), U4.1 (A0), U5.1 (A0), U7.1 (A0), U8.1 (A0), U10.1 (A0), U11.1 (A0), U20.4 (Za)
/Address Selector/SAddr1: U1.15 (A1), U2.15 (A1), U4.15 (A1), U5.15 (A1), U7.15 (A1), U8.15 (A1), U10.15 (A1), U11.15 (A1), U20.7 (Zb)
/Address Selector/SAddr2: U1.14 (A2), U2.14 (A2), U4.14 (A2), U5.14 (A2), U7.14 (A2), U8.14 (A2), U10.14 (A2), U11.14 (A2), U20.9 (Zc)
/Address Selector/SAddr3: U1.13 (A3), U2.13 (A3), U4.13 (A3), U5.13 (A3), U7.13 (A3), U8.13 (A3), U10.13 (A3), U11.13 (A3), U20.12 (Zd)
/Address Selector/SAddr4: U17.14 (A0), U21.4 (Za)
/Address Selector/SAddr5: U17.13 (A1), U21.7 (Zb)
/Address Selector/counter_CLK: U18.2 (CP), U19.2 (CP), U23.9, U24.2
/Control Logic/CLK: J1.1 (Pin_1_1), R3.1, U24.13
/Control Logic/RAM_WE: U1.3 (WE), U2.3 (WE), U4.3 (WE), U5.3 (WE), U7.3 (WE), U8.3 (WE), U10.3 (WE), U11.3 (WE), U23.3
/Control Logic/man_HLT: HLT.2, R2.2, U23.12
/Control Logic/word_CLK: U15.9, U24.1, U24.12
/Control Logic/word_HLT: U15.8, U23.2, U23.13
/Din0: J3.1, R5.1, U2.4 (D0), U5.4 (D0), U8.4 (D0), U11.4 (D0), U14.10 (A0)
/Din1: J3.2, R6.1, U2.6 (D1), U5.6 (D1), U8.6 (D1), U11.6 (D1), U14.12 (A1)
/Din2: J3.3, R7.1, U2.10 (D2), U5.10 (D2), U8.10 (D2), U11.10 (D2), U14.13 (A2)
/Din3: J3.4, R8.1, U2.12 (D3), U5.12 (D3), U8.12 (D3), U11.12 (D3), U14.15 (A3)
/Din4: J3.5, R9.1, U1.4 (D0), U4.4 (D0), U7.4 (D0), U10.4 (D0), U13.10 (A0)
/Din5: J3.6, R10.1, U1.6 (D1), U4.6 (D1), U7.6 (D1), U10.6 (D1), U13.12 (A1)
/Din6: J3.7, R11.1, U1.10 (D2), U4.10 (D2), U7.10 (D2), U10.10 (D2), U13.13 (A2)
/Din7: J3.8, R12.1, U1.12 (D3), U4.12 (D3), U7.12 (D3), U10.12 (D3), U13.15 (A3)
/Out0: J6.8, U3.18 (B0), U6.18 (B0), U9.18 (B0), U12.18 (B0)
/Out1: J6.7, U3.17 (B1), U6.17 (B1), U9.17 (B1), U12.17 (B1)
/Out2: J6.6, U3.16 (B2), U6.16 (B2), U9.16 (B2), U12.16 (B2)
/Out3: J6.5, U3.15 (B3), U6.15 (B3), U9.15 (B3), U12.15 (B3)
/Out4: J6.4, U3.14 (B4), U6.14 (B4), U9.14 (B4), U12.14 (B4)
/Out5: J6.3, U3.13 (B5), U6.13 (B5), U9.13 (B5), U12.13 (B5)
/Out6: J6.2, U3.12 (B6), U6.12 (B6), U9.12 (B6), U12.12 (B6)
/Out7: J6.1, U3.11 (B7), U6.11 (B7), U9.11 (B7), U12.11 (B7)
/Win0: J4.1, U14.9 (B0)
/Win1: J4.2, U14.11 (B1)
/Win2: J4.3, U14.14 (B2)
/Win3: J4.4, U14.1 (B3)
/Win4: J4.5, U13.9 (B0)
/Win5: J4.6, U13.11 (B1)
/Win6: J4.7, U13.14 (B2)
/Win7: J4.8, U13.1 (B3)
/Word Comparator/word_EN: R4.1, U15.10, W_EN.2
GND: C1.2, C2.2, C3.2, C4.2, C5.2, C6.2, C7.2, C8.2, C9.2, C10.2, C11.2, C12.2, C13.1, C14.1, C15.1, C16.1, C17.2, C18.1, C19.1, C20.1, C21.1, C22.1, C23.1, C24.1, J5.2, R2.1, R4.2, R5.2, R6.2, R7.2, R8.2, R9.2, R10.2, R11.2, R12.2, RUN.1, U1.8 (GND), U2.8 (GND), U3.10 (GND), U4.8 (GND), U5.8 (GND), U6.10 (GND), U7.8 (GND), U8.8 (GND), U9.10 (GND), U10.8 (GND), U11.8 (GND), U12.10 (GND), U13.2 (Ia<b), U13.4 (Ia>b), U13.8 (GND), U14.2 (Ia<b), U14.4 (Ia>b), U14.8 (GND), U15.7 (GND), U16.7 (GND), U17.2 (A0), U17.3 (A1), U17.8 (GND), U17.15 (E), U18.3 (D0), U18.4 (D1), U18.5 (D2), U18.6 (D3), U18.8 (GND), U19.3 (D0), U19.4 (D1), U19.5 (D2), U19.6 (D3), U19.8 (GND), U20.8 (GND), U20.15 (E), U21.8 (GND), U21.10 (I1c), U21.11 (I0c), U21.13 (I1d), U21.14 (I0d), U21.15 (E), U22.8 (GND), U23.7 (GND), U24.7 (GND)
unnamed: U1.5 (O0), U3.6 (A4)
unnamed: U1.7 (O1), U3.7 (A5)
unnamed: U1.9 (O2), U3.8 (A6)
unnamed: U1.11 (O3), U3.9 (A7)
unnamed: U2.5 (O0), U3.2 (A0)
unnamed: U2.7 (O1), U3.3 (A1)
unnamed: U2.9 (O2), U3.4 (A2)
unnamed: U2.11 (O3), U3.5 (A3)
unnamed: U4.5 (O0), U6.6 (A4)
unnamed: U4.7 (O1), U6.7 (A5)
unnamed: U4.9 (O2), U6.8 (A6)
unnamed: U4.11 (O3), U6.9 (A7)
unnamed: U5.5 (O0), U6.2 (A0)
unnamed: U5.7 (O1), U6.3 (A1)
unnamed: U5.9 (O2), U6.4 (A2)
unnamed: U5.11 (O3), U6.5 (A3)
unnamed: U7.5 (O0), U9.6 (A4)
unnamed: U7.7 (O1), U9.7 (A5)
unnamed: U7.9 (O2), U9.8 (A6)
unnamed: U7.11 (O3), U9.9 (A7)
unnamed: U8.5 (O0), U9.2 (A0)
unnamed: U8.7 (O1), U9.3 (A1)
unnamed: U8.9 (O2), U9.4 (A2)
unnamed: U8.11 (O3), U9.5 (A3)
unnamed: U10.5 (O0), U12.6 (A4)
unnamed: U10.7 (O1), U12.7 (A5)
unnamed: U10.9 (O2), U12.8 (A6)
unnamed: U10.11 (O3), U12.9 (A7)
unnamed: U11.5 (O0), U12.2 (A0)
unnamed: U11.7 (O1), U12.3 (A1)
unnamed: U11.9 (O2), U12.4 (A2)
unnamed: U11.11 (O3), U12.5 (A3)
unnamed: U13.6 (Oa=b), U15.13
unnamed: U14.6 (Oa=b), U15.12
unnamed: U18.14 (Q0), U20.3 (I1a)
unnamed: U18.13 (Q1), U20.6 (I1b)
unnamed: U18.12 (Q2), U20.10 (I1c)
unnamed: U18.11 (Q3), U20.13 (I1d)
unnamed: U18.15 (TC), U19.10 (CET)
unnamed: U19.14 (Q0), U21.3 (I1a)
unnamed: U19.13 (Q1), U21.6 (I1b)
unnamed: U22.14 (~R), U24.8
unnamed: U23.1, U23.8
unnamed: U23.10, U24.10
unnamed: U23.11, U24.9

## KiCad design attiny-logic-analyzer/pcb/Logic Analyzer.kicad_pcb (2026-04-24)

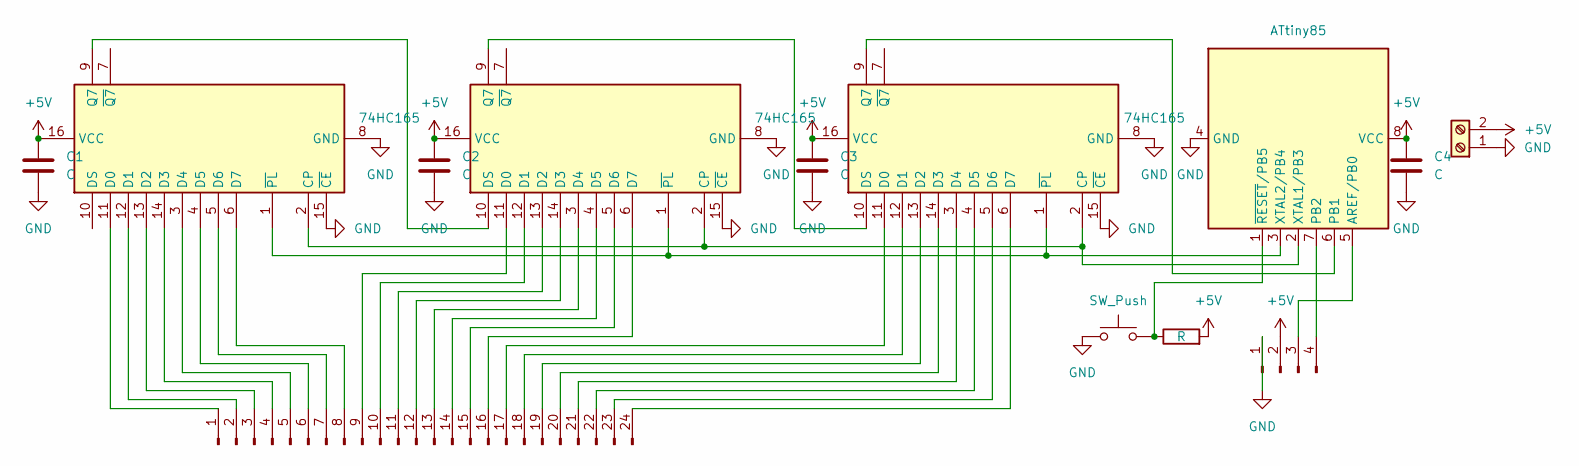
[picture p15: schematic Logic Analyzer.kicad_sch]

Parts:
C1, C2, C3, C4: C; C_Disc_D7.0mm_W2.5mm_P5.00mm
J1: Conn_01x24_Pin; PinHeader_1x24_P2.54mm_Vertical
J2: Conn_01x04_Pin; PinHeader_1x04_P2.54mm_Vertical
J3: Screw_Terminal_01x02; TerminalBlock_Phoenix_MKDS-1,5-2-5.08_1x02_P5.08mm_Horizont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
R1: R; R_Axial_DIN0207_L6.3mm_D2.5mm_P7.62mm_Horizontal
SW1: SW_Push; SW_PUSH_6mm
U1, U2, U3: 74HC165; DIP-16_W7.62mm
U4: ATtiny85; DIP-8_W7.62mm

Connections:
+5V: C1.1, C2.1, C3.1, C4.1, J2.2, J3.2, R1.2, U1.16 (VCC), U2.16 (VCC), U3.16 (VCC), U4.8 (VCC)
GND: C1.2, C2.2, C3.2, C4.2, J2.1, J3.1, SW1.1, U1.8 (GND), U1.15 (~CE), U2.8 (GND), U2.15 (~CE), U3.8 (GND), U3.15 (~CE), U4.4 (GND)
unnamed: J1.1, U1.11 (D0)
unnamed: J1.2, U1.12 (D1)
unnamed: J1.3, U1.13 (D2)
unnamed: J1.4, U1.14 (D3)
unnamed: J1.5, U1.3 (D4)
unnamed: J1.6, U1.4 (D5)
unnamed: J1.7, U1.5 (D6)
unnamed: J1.8, U1.6 (D7)
unnamed: J1.9, U2.11 (D0)
unnamed: J1.10, U2.12 (D1)
unnamed: J1.11, U2.13 (D2)
unnamed: J1.12, U2.14 (D3)
unnamed: J1.13, U2.3 (D4)
unnamed: J1.14, U2.4 (D5)
unnamed: J1.15, U2.5 (D6)
unnamed: J1.16, U2.6 (D7)
unnamed: J1.17, U3.11 (D0)
unnamed: J1.18, U3.12 (D1)
unnamed: J1.19, U3.13 (D2)
unnamed: J1.20, U3.14 (D3)
unnamed: J1.21, U3.3 (D4)
unnamed: J1.22, U3.4 (D5)
unnamed: J1.23, U3.5 (D6)
unnamed: J1.24, U3.6 (D7)
unnamed: J2.3, U4.5 (AREF/PB0)
unnamed: J2.4, U4.7 (PB2)
unnamed: U1.2 (CP), U2.2 (CP), U3.2 (CP), U4.2 (XTAL1/PB3)
unnamed: U1.9 (Q7), U2.10 (DS)
unnamed: U1.1 (~PL), U2.1 (~PL), U3.1 (~PL), U4.3 (XTAL2/PB4)
unnamed: U2.9 (Q7), U3.10 (DS)
unnamed: U3.9 (Q7), U4.6 (PB1)
unnamed: R1.1, SW1.2, U4.1 (~RESET/PB5)

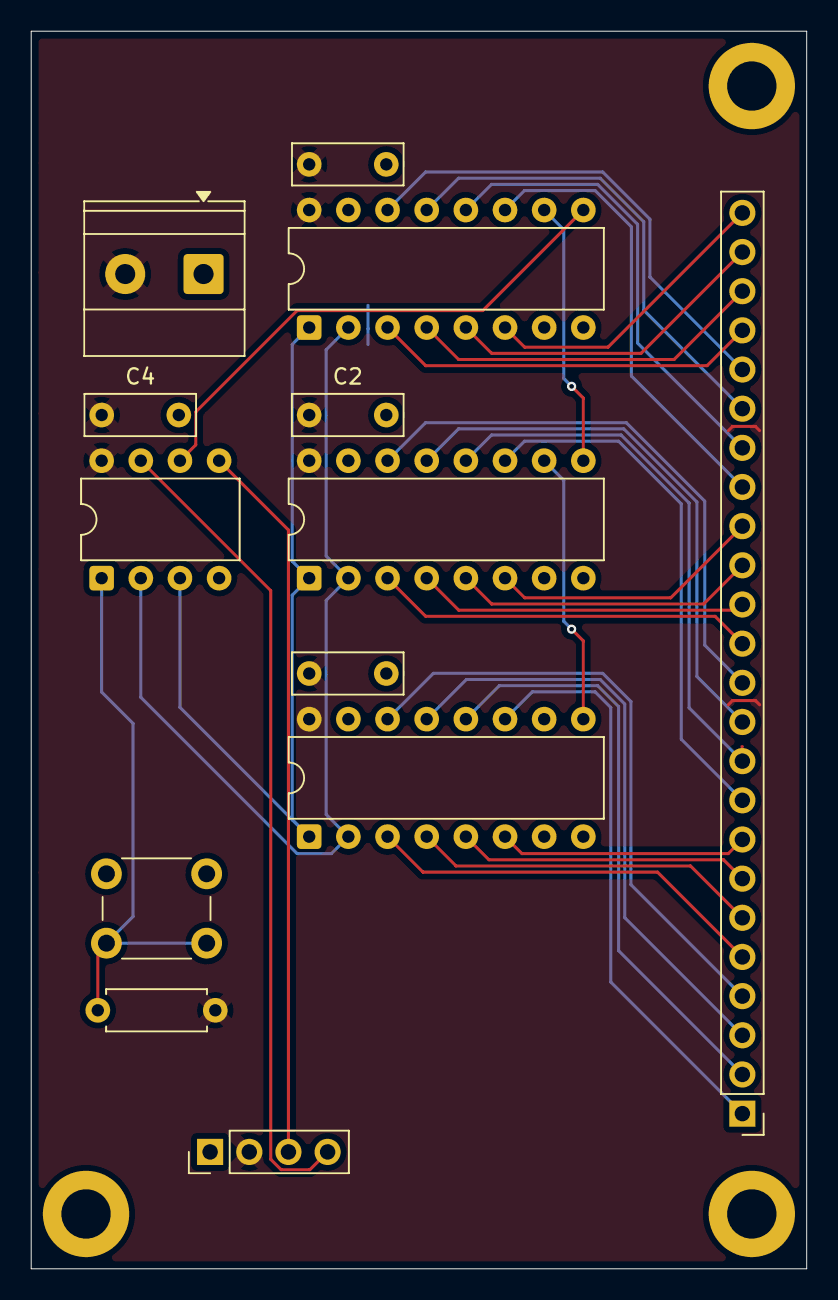
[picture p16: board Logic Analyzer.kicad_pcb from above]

Board: 2 copper layers, 50.3 x 80.3 mm, 13 parts (0 on the bottom side), 34 nets.

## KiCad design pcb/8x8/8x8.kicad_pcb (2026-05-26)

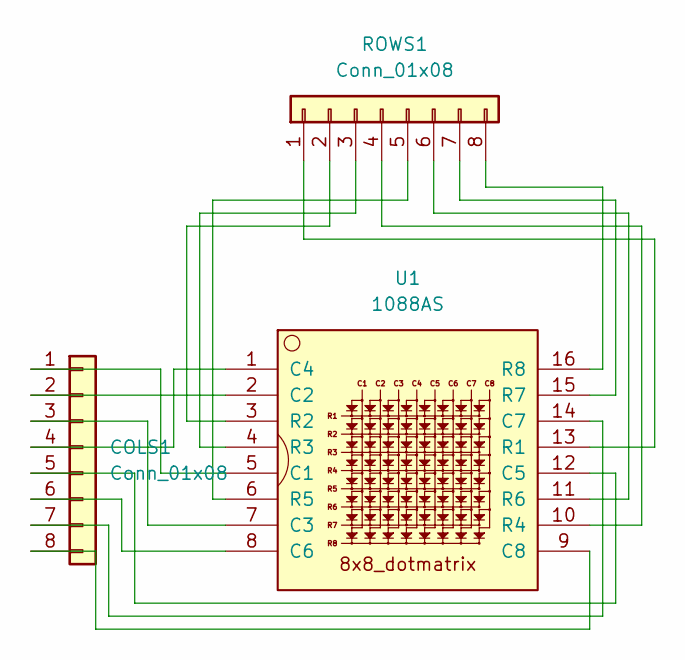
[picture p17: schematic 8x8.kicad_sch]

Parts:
COLS1: Conn_01x08; PinSocket_1x08_P2.54mm_Vertical
ROWS1: Conn_01x08; PinSocket_1x08_P2.54mm_Vertical
U1: 1088AS; LED_1088_Pin_Header

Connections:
unnamed: COLS1.1, U1.5 (C1)
unnamed: COLS1.2, U1.2 (C2)
unnamed: COLS1.3, U1.7 (C3)
unnamed: COLS1.4, U1.1 (C4)
unnamed: COLS1.5, U1.12 (C5)
unnamed: COLS1.6, U1.8 (C6)
unnamed: COLS1.7, U1.14 (C7)
unnamed: COLS1.8, U1.9 (C8)
unnamed: ROWS1.1, U1.13 (R1)
unnamed: ROWS1.2, U1.3 (R2)
unnamed: ROWS1.3, U1.4 (R3)
unnamed: ROWS1.4, U1.10 (R4)
unnamed: ROWS1.5, U1.6 (R5)
unnamed: ROWS1.6, U1.11 (R6)
unnamed: ROWS1.7, U1.15 (R7)
unnamed: ROWS1.8, U1.16 (R8)

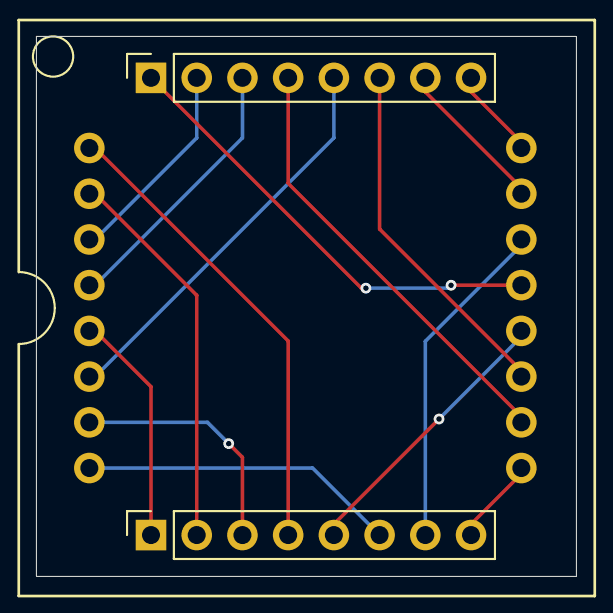
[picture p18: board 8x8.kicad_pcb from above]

Board: 2 copper layers, 30.0 x 30.0 mm, 3 parts (0 on the bottom side), 16 nets.

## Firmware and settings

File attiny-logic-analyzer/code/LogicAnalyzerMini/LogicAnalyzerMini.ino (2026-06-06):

// ATtiny85 + 74HC165 logic analyzer

#include <TinyWireM.h>
#include <LiquidCrystal_I2C.h>

LiquidCrystal_I2C lcd(0x27, 16, 2);

const uint8_t dataPin = 1;   // phys pin 6
const uint8_t clockPin = 3; // phys pin 2
const uint8_t latchPin = 4; // phys pin 3

uint16_t addr; // hex address (4 digits)
uint8_t dat; // hex data (2 digits)

void printBinFixed(uint16_t num, uint8_t digits) {
  for (int i = digits - 1; i >= 0; i--) {
    lcd.print(num >> i & 1);  
  }
}
void printHexFixed(uint16_t num, uint8_t digits) { // print hex to lcd
  for (int i = (digits - 1) * 4; i >= 0; i -= 4) {
    lcd.print((num >> i) & 0xF, HEX);
  }
}

void setup() {
  TinyWireM.begin();
  lcd.init();
  lcd.backlight();

  pinMode(dataPin, INPUT_PULLUP);
  pinMode(clockPin, OUTPUT);
  pinMode(latchPin, OUTPUT);

  digitalWrite(clockPin, LOW);
  digitalWrite(latchPin, HIGH);

  lcd.setCursor(0, 0);
  lcd.print("ADDR:0000");
  lcd.setCursor(0, 1);
  lcd.print("DATA:00");
}

void loop() { // DAISY-CHAINED TO READ LSB FIRST
  addr = 0;
  dat = 0;

  // load parallel inputs into 74HC165
  digitalWrite(latchPin, LOW);
  delayMicroseconds(5);
  digitalWrite(latchPin, HIGH);
  delayMicroseconds(5);

  // read first 8 bits (data)
  for (int i = 0; i < 8; i++) {
    dat |= ((uint16_t) digitalRead(dataPin) << i);
    digitalWrite(clockPin, HIGH);
    delayMicroseconds(2);
    digitalWrite(clockPin, LOW);
    delayMicroseconds(2);
  }

  // read next 16 bits (address)
  for (int i = 0; i < 16; i++) {
    addr |= ((uint16_t) digitalRead(dataPin) << i);
    digitalWrite(clockPin, HIGH);
    delayMicroseconds(2);
    digitalWrite(clockPin, LOW);
    delayMicroseconds(2);
  }

  lcd.setCursor(5, 0);
  printBinFixed(addr, 16);
  lcd.setCursor(5, 1);
  printBinFixed(dat, 8);
  delay(150);
}

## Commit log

2026-05-12 File architecture edited, 8x8 dotmat pcb added
    [.kicad_sch.kicad_sch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]
2026-05-25 Improving docs Added architecture.md to give current plan for memory side layout
2026-05-26 chore: add gitignore
    [.kicad_sch.kicad_sch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]
2026-05-27 Chore: cleaned .gitignore files
    [.kicad_sch.kicad_sch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]
2026-05-27 Updated build log
    [.kicad_sch.kicad_sch, Logic Analyzer.kicad_pcb, Logic Analyzer.kicad_sch]
2026-05-27 Adjusted to match current design
2026-06-06 Secondary project repository added
    [.kicad_sch.kicad_sch, Logic Analyzer.kicad_pcb, Logic Analyzer.kicad_sch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]
2026-06-08 HLT Word operation fixed to fit current design
2026-06-14 Started memory subsystem schematic
    [RAM_unit.kicad_sch, memory_subsystem.kicad_sch]
2026-06-22 Finished first draft of memory subsystem
    [RAM_selector.kicad_sch, address_selector.kicad_sch, control_logic.kicad_sch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]
2026-07-10 Fixed spacing problem: no warnings/erros
    [RAM_unit.kicad_sch, address_selector.kicad_sch, control_logic.kicad_sch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]
2026-07-10 Footprints asssigned
    [RAM_unit.kicad_sch, memory_subsystem.kicad_pcb]
2026-07-11 Tracks finished
    [RAM_unit.kicad_sch, address_selector.kicad_sch, control_logic.kicad_sch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]
2026-07-13 Finished mem subsystem pcb
    [RAM_unit.kicad_sch, memory_subsystem.kicad_pcb, memory_subsystem.kicad_sch]
